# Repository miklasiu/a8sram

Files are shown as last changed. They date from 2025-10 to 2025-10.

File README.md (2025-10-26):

Atari 8bit Freddy and DRAM chips replacement.
---------------------------------------------

I created it because I had 32k SRAM chips available and needed to test if my Freddy was working (it was).
The board is intended for home manufacturing. There is only 1 via. I was able to do it using 3d printer with drill attachment and laser printer thermo-transfer. Make sure to solder on both sides where necessary or tell me how to make vias/holes conductive at home.

There are more reasonable Freddy and SRAM replacements avialble:

Pre-built:
- https://retrolemon.co.uk/atari-8bit-upgrades/81-freddie-module.html
- https://lotharek.pl/productdetail.php?id=233
- https://retrolemon.co.uk/atari-8bit-upgrades/114-sram-64kb.html
- https://lotharek.pl/productdetail.php?id=291

Schematics:
- https://github.com/prcoder-1/a8-sram64kb
  
What's left from Freddy is then just frequency /4 divider you can do on 7474.

Finished thing:
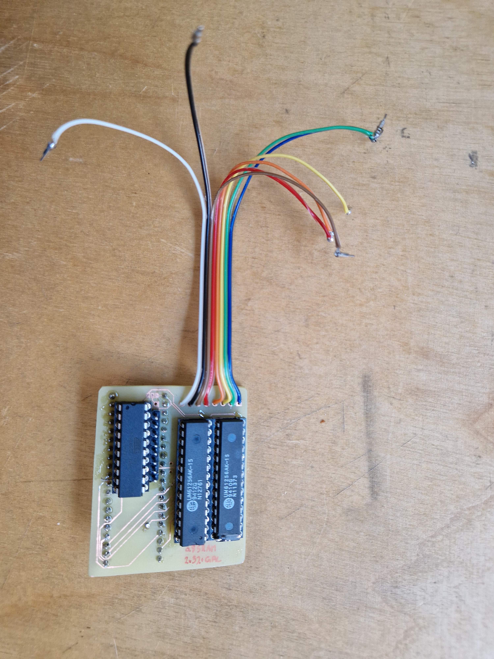
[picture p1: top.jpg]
top

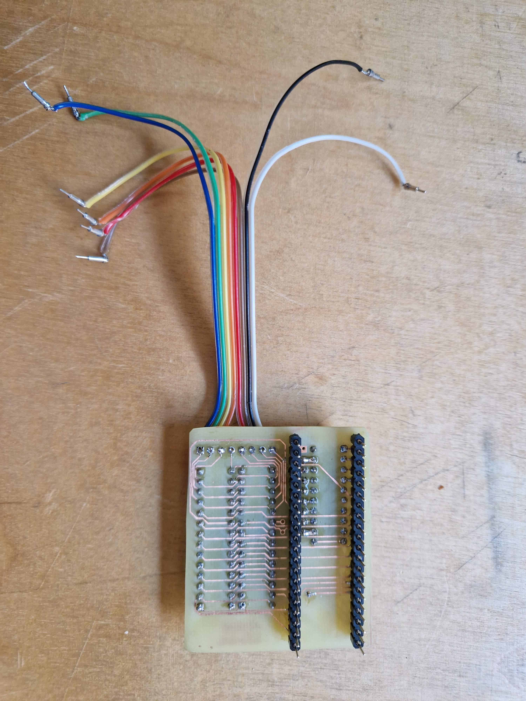
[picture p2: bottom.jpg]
bottom


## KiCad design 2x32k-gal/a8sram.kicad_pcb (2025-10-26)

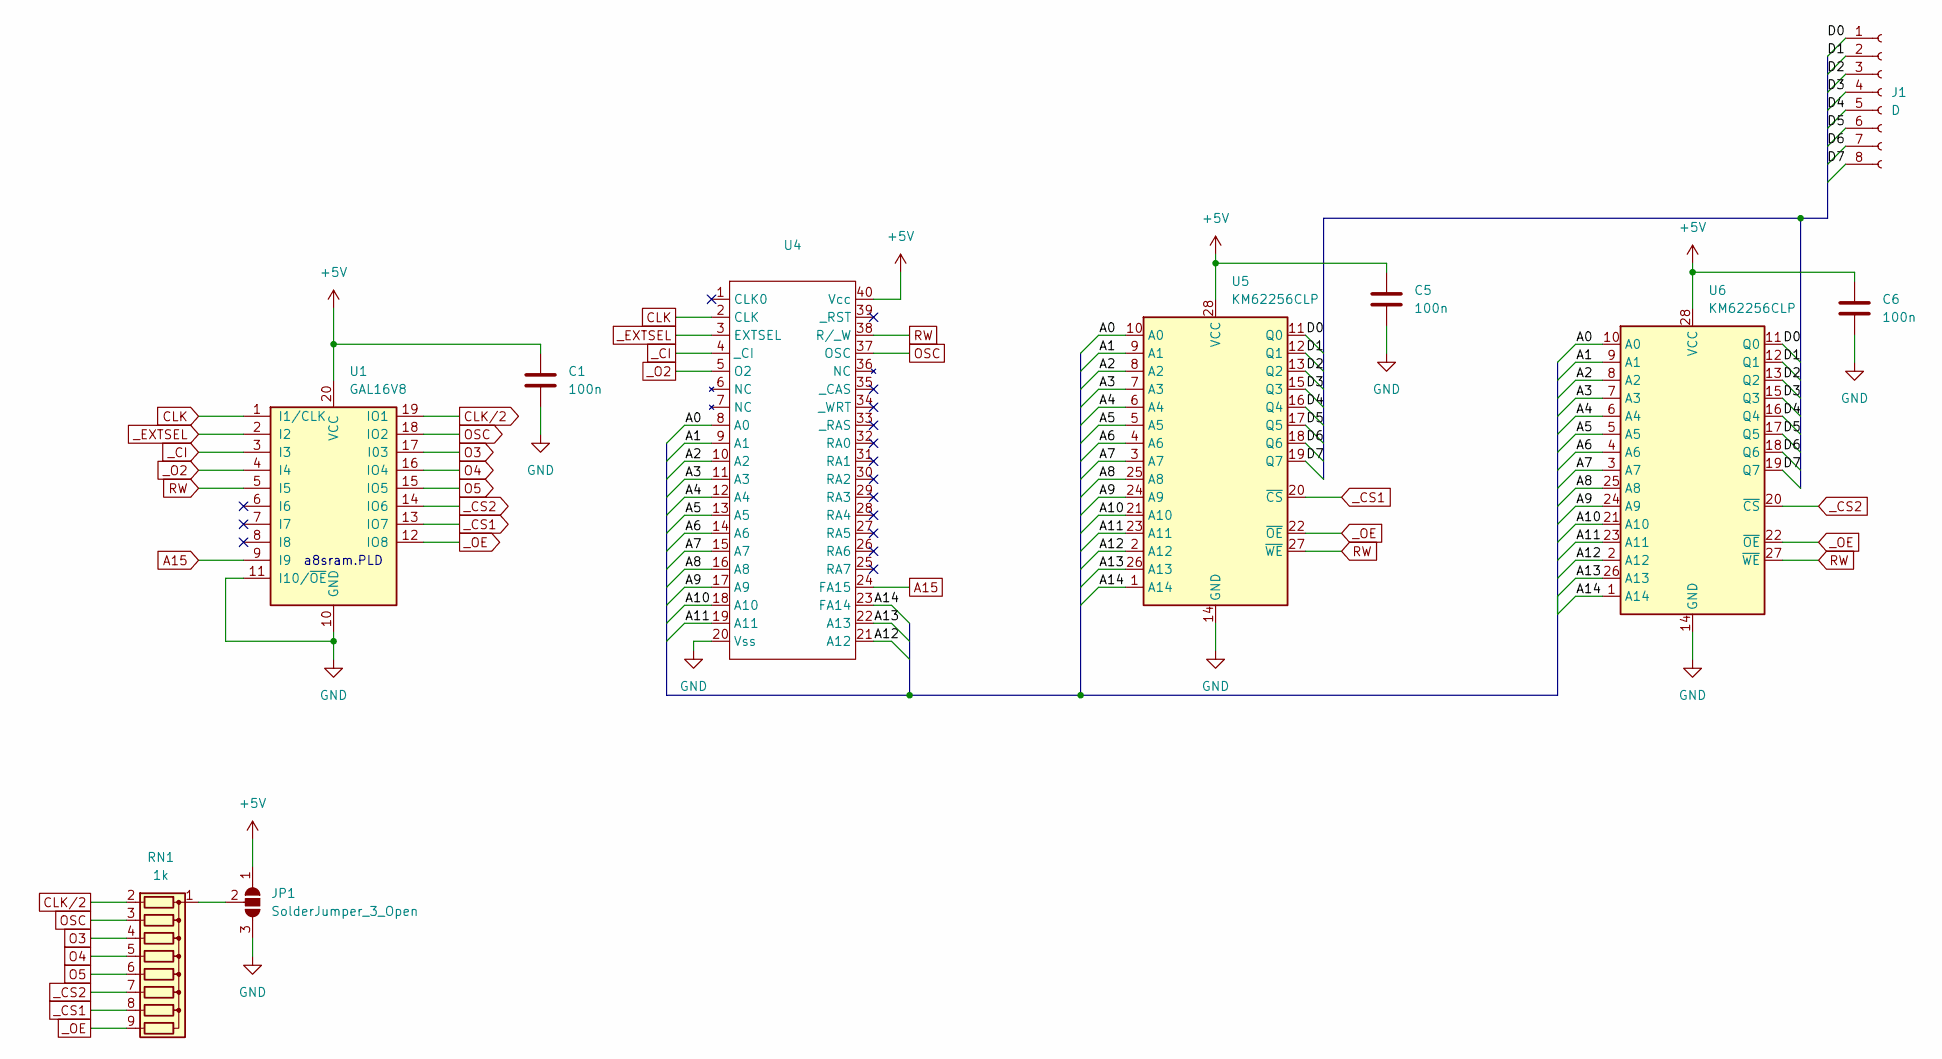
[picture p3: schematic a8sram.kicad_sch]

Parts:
C1, C5, C6: 100n; C_0805_2012Metric_Pad1.18x1.45mm_HandSolder
J1: D; PinHeader_1x08_P2.54mm_Vertical
JP1: SolderJumper_3_Open; SolderJumper-3_P1.3mm_Open_RoundedPad1.0x1.5mm
RN1: 1k; R_Array_SIP9
U1: GAL16V8; DIP-20_W7.62mm
U4: DIP-40_W15.24mm
U5, U6: KM62256CLP; DIP-28_W7.62mm

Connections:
+5V: C1.1, C5.1, C6.1, JP1.1 (A), U1.20 (VCC), U4.40 (Vcc), U5.28 (VCC), U6.28 (VCC)
/A0: U4.8 (A0), U5.10 (A0), U6.10 (A0)
/A1: U4.9 (A1), U5.9 (A1), U6.9 (A1)
/A2: U4.10 (A2), U5.8 (A2), U6.8 (A2)
/A3: U4.11 (A3), U5.7 (A3), U6.7 (A3)
/A4: U4.12 (A4), U5.6 (A4), U6.6 (A4)
/A5: U4.13 (A5), U5.5 (A5), U6.5 (A5)
/A6: U4.14 (A6), U5.4 (A6), U6.4 (A6)
/A7: U4.15 (A7), U5.3 (A7), U6.3 (A7)
/A8: U4.16 (A8), U5.25 (A8), U6.25 (A8)
/A9: U4.17 (A9), U5.24 (A9), U6.24 (A9)
/A10: U4.18 (A10), U5.21 (A10), U6.21 (A10)
/A11: U4.19 (A11), U5.23 (A11), U6.23 (A11)
/A12: U4.21 (A12), U5.2 (A12), U6.2 (A12)
/A13: U4.22 (A13), U5.26 (A13), U6.26 (A13)
/A14: U4.23 (FA14), U5.1 (A14), U6.1 (A14)
/D0: J1.1, U5.11 (Q0), U6.11 (Q0)
/D1: J1.2, U5.12 (Q1), U6.12 (Q1)
/D2: J1.3, U5.13 (Q2), U6.13 (Q2)
/D3: J1.4, U5.15 (Q3), U6.15 (Q3)
/D4: J1.5, U5.16 (Q4), U6.16 (Q4)
/D5: J1.6, U5.17 (Q5), U6.17 (Q5)
/D6: J1.7, U5.18 (Q6), U6.18 (Q6)
/D7: J1.8, U5.19 (Q7), U6.19 (Q7)
A15: U1.9 (I9), U4.24 (FA15)
CLK: U1.1 (I1/CLK), U4.2 (CLK)
CLK/2: RN1.2 (R1), U1.19 (IO1)
GND: C1.2, C5.2, C6.2, JP1.3 (B), U1.10 (GND), U1.11 (I10/~OE), U4.20 (Vss), U5.14 (GND), U6.14 (GND)
unnamed: JP1.2 (C), RN1.1 (common)
O3: RN1.4 (R3), U1.17 (I03)
O4: RN1.5 (R4), U1.16 (IO4)
O5: RN1.6 (R5), U1.15 (IO5)
OSC: RN1.3 (R2), U1.18 (IO2), U4.37 (OSC)
RW: U1.5 (I5), U4.38 (R/_W), U5.27 (~WE), U6.27 (~WE)
_CI: U1.3 (I3), U4.4 (_CI)
_CS1: RN1.8 (R7), U1.13 (IO7), U5.20 (~CS)
_CS2: RN1.7 (R6), U1.14 (IO6), U6.20 (~CS)
_EXTSEL: U1.2 (I2), U4.3 (EXTSEL)
_O2: U1.4 (I4), U4.5 (O2)
_OE: RN1.9 (R8), U1.12 (IO8), U5.22 (~OE), U6.22 (~OE)

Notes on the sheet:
a8sram.PLD

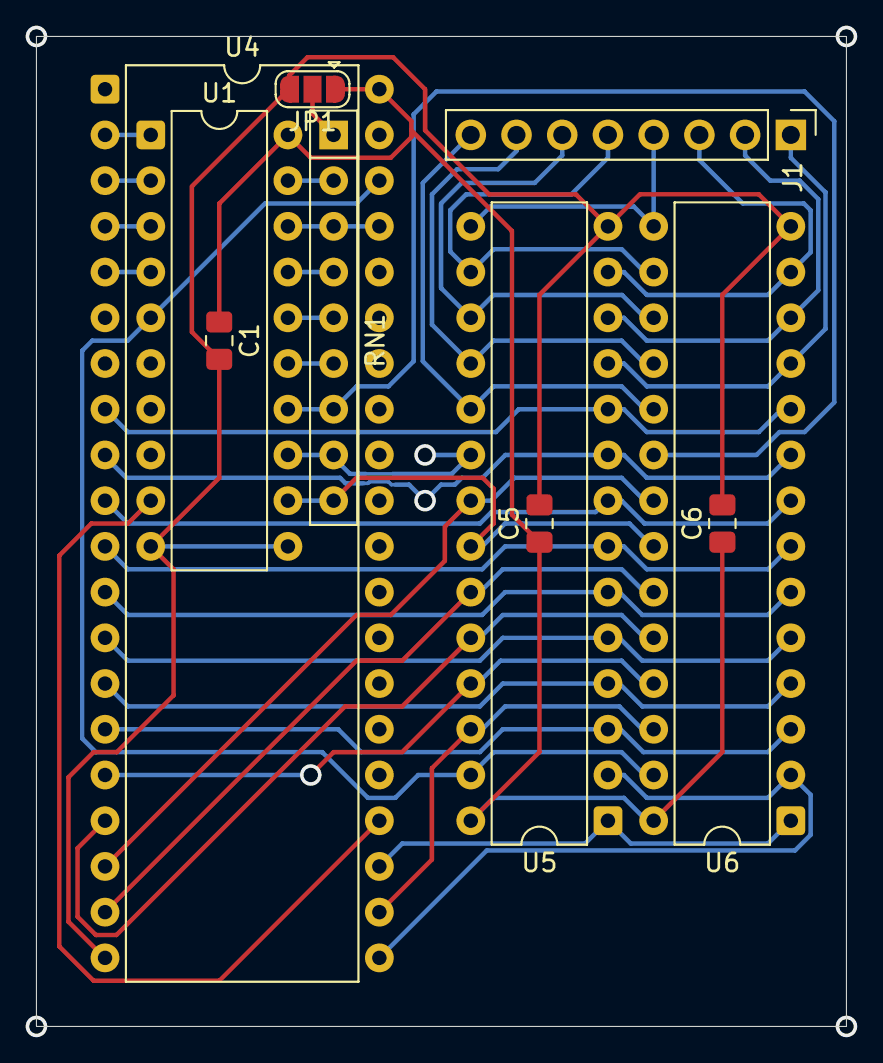
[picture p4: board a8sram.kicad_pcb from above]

Board: 2 copper layers, 45.0 x 55.0 mm, 10 parts (0 on the bottom side), 40 nets.

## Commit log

2025-10-21 2x32k-gal works!
    [a8sram-B_Cu.gbr, a8sram-B_Silkscreen.gbr, a8sram-Edge_Cuts.gbr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]
2025-10-26 Enhance README with manufacturing and soldering info
